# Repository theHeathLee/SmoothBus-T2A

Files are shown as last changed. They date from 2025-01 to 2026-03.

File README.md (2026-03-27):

# SmoothBus T2A

An adaptation of the [SmoothBus project](https://github.com/PegorK/SmoothBus/tree/main) for the early VW bay window bus (Type 2A). Replaces the original fuel gauge mechanism with a servo-driven needle controlled by an ATTiny85 microcontroller, providing smooth movement and a low-fuel LED warning.

## Features

- Smooth servo motion — moves in 1° steps with a moving average filter (35-sample window) to eliminate sender noise
- Low-fuel LED warning when the sender reads in the reserve range
- Boot sweep sequence (empty → full → empty) to verify servo operation
- Compact PCB (~32mm × 14mm) designed to fit within the original gauge enclosure
- 3D-printable enclosure included

## How It Works

The ATTiny85 reads the fuel sender resistance via a voltage divider, applies a running average to smooth noisy readings, and drives a servo to the corresponding needle position. Calibration values are sourced from the [TheSamba forum](https://www.thesamba.com/vw/forum/viewtopic.php?t=693930) and tuned for the T2A sender:

| Sender (Ω) | Level | Servo angle |
|---|---|---|
| 10 | Full | 10° |
| 40 | Half | 53° |
| 55 | Quarter | 71° |
| 70 | Reserve | 81° |
| 79 | Empty | 98° |

## Repository Layout

```
SmoothBus-T2A/
├── src/SmoothBus/SmoothBus.ino   # ATTiny85 firmware (Arduino)
├── hardware/
│   ├── SmoothBusT2A.kicad_sch    # Schematic
│   ├── SmoothBusT2A.kicad_pcb    # PCB layout
│   ├── SmoothBusT2A.pdf          # Schematic PDF
│   ├── gerbers.zip               # Gerber files for PCB fabrication
│   ├── bom/ibom.html             # Interactive BOM
│   └── 3D Parts/body.stl         # 3D-printable enclosure
└── pictures/                     # Assembly and finished photos
```

## Resources

- [Interactive BOM](https://htmlpreview.github.io/?https://github.com/theHeathLee/SmoothBus-T2A/blob/main/hardware/bom/ibom.html)
- [Schematic PDF](https://github.com/theHeathLee/SmoothBus-T2A/blob/main/hardware/SmoothBusT2A.pdf)
- [Firmware README](src/README.md) — flashing instructions (Arduino Mega as ISP + ATTinyCore)

## Photos

<table>
  <tr>
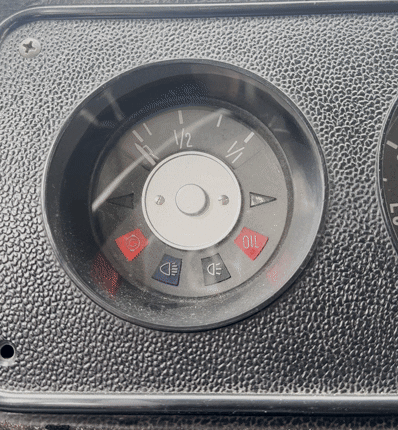
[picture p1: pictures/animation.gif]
Animation
    <td></td>
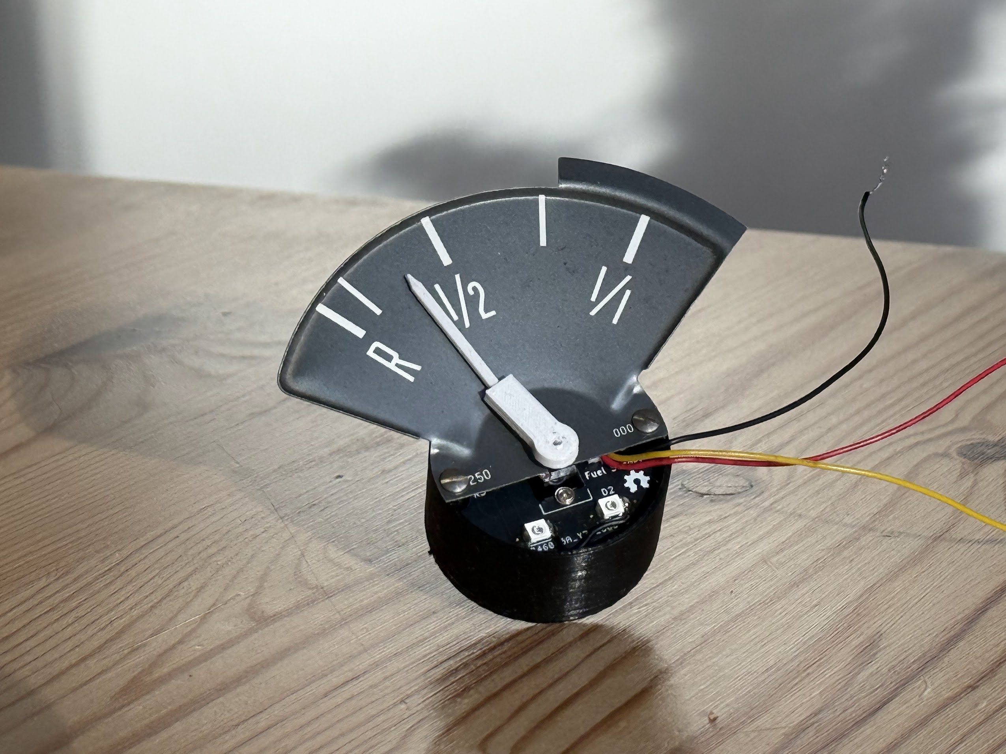
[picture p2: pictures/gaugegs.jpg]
Gauge
    <td></td>
  </tr>
  <tr>
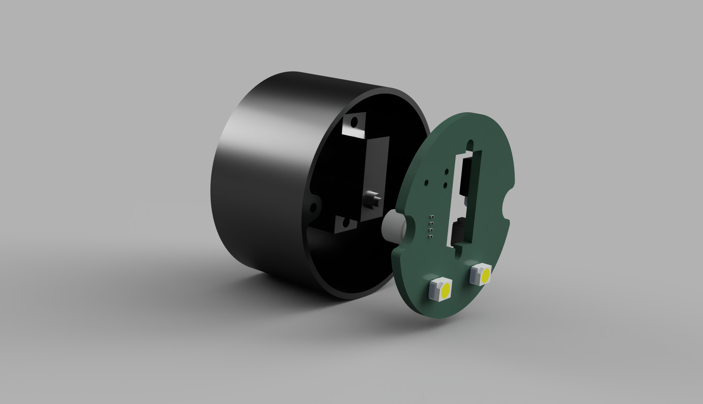
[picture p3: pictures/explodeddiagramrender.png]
Exploded view render
    <td></td>
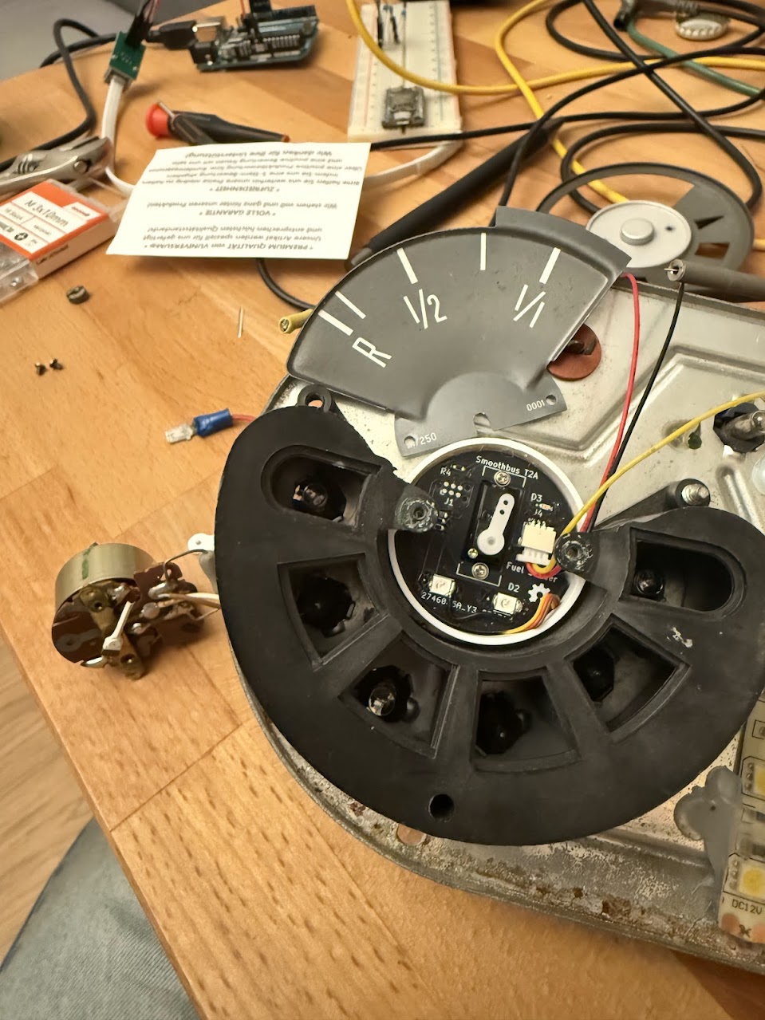
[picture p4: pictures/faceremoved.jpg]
Face removed
    <td></td>
  </tr>
  <tr>
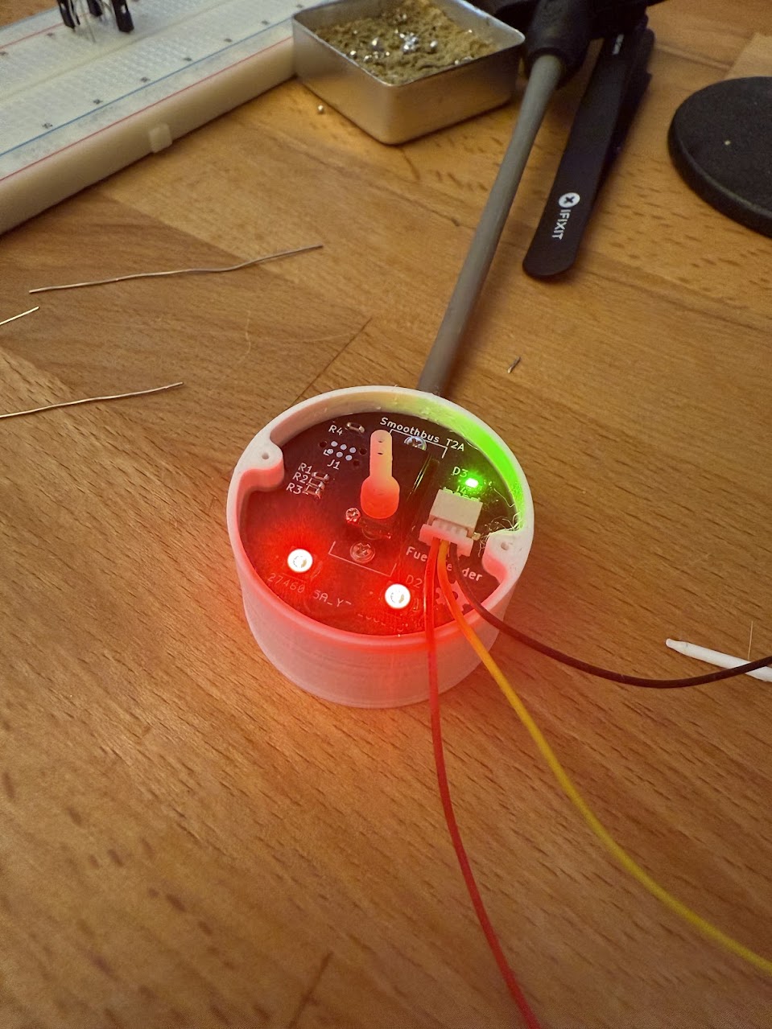
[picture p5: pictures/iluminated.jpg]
Illuminated
    <td></td>
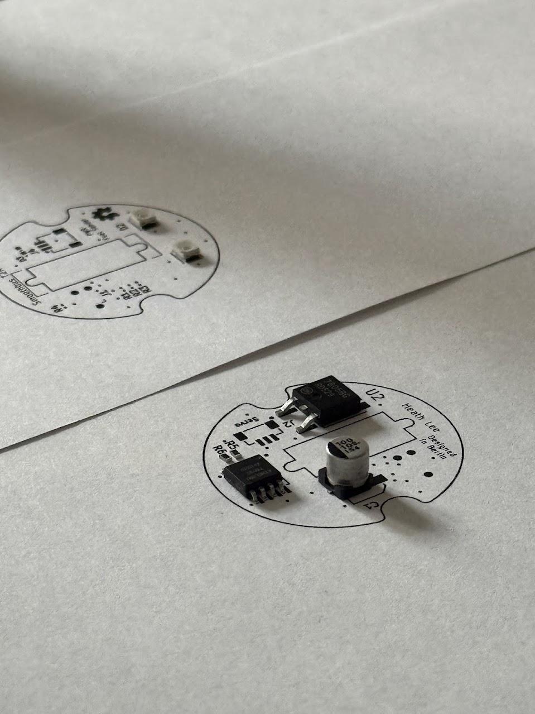
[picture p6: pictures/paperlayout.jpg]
Paper layout
    <td></td>
  </tr>
</table>

## Credits

Original SmoothBus design by [Pegor Karoglanian](https://github.com/PegorK/SmoothBus/tree/main).

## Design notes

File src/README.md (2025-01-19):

# SmoothBus Src

This folder contains the code that gets slapped onto the ATTiny85 chip using the Arduino IDE.

### Dependencies

* [Konde's ATTinyCore library](https://github.com/SpenceKonde/ATTinyCore) - add to your Arduino IDE.

### Flashing

* I used an Arduino Mega2560 as an ISP to flash the ATTiny85 with the programming jig. [Here](https://www.instructables.com/How-to-Burn-ATTiny85-Using-Arduino-Mega/) is a decent write up.
    * Flashed the ATTiny85 with the clock set to 16 Mhz, anything less with introduce more servo jitter.

## Things to improve
* Discard readings that are dramatically different than previous reading. Could be based on percent difference.
* Low fuel warning indicator logic could be improved to not trigger on every time it has a reading in that range. Instead turn the warning lights on if there has been continuous readings in that range (maybe something along the lines of if 20 readings) same with turning them off. This could help reduce flashing warning lights when you take a turn.

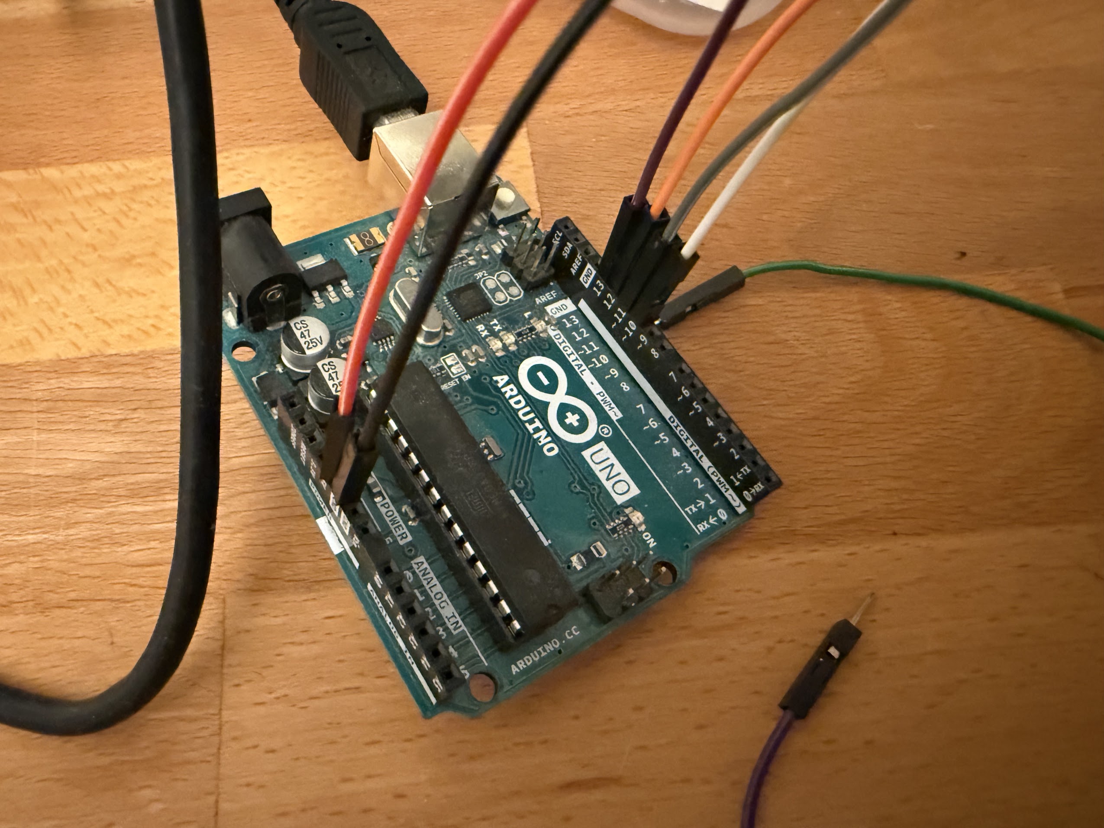
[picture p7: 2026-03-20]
pictures/uno.png

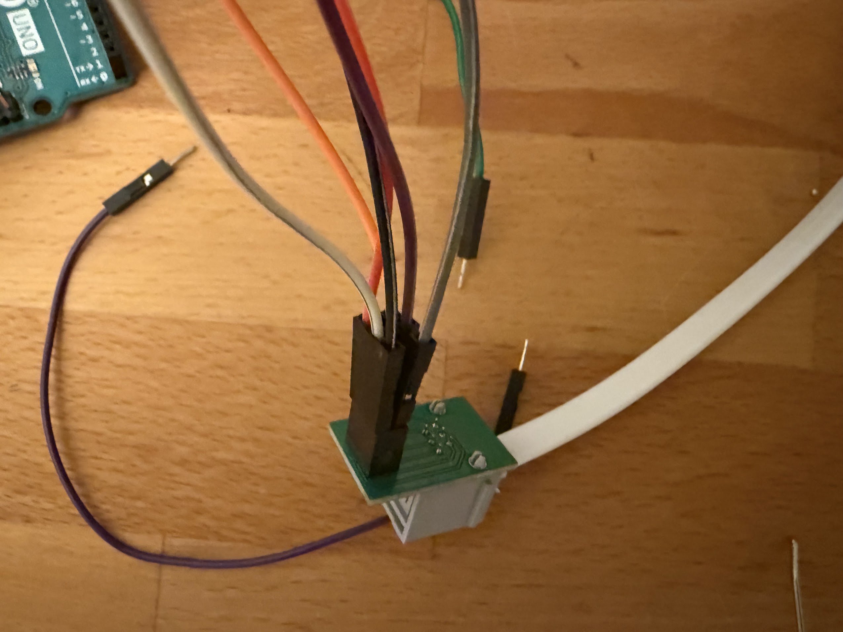
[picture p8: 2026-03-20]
pictures/tagconnect.png

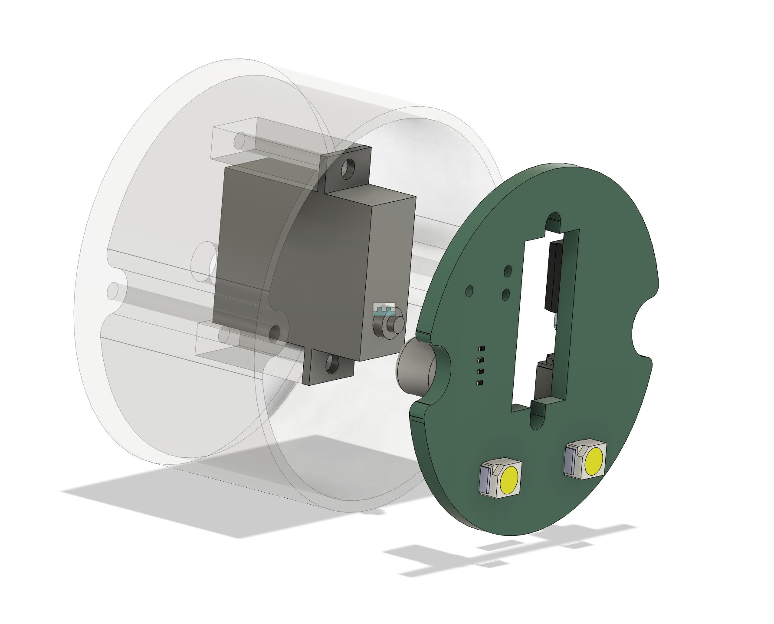
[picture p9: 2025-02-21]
pictures/explodedview.png

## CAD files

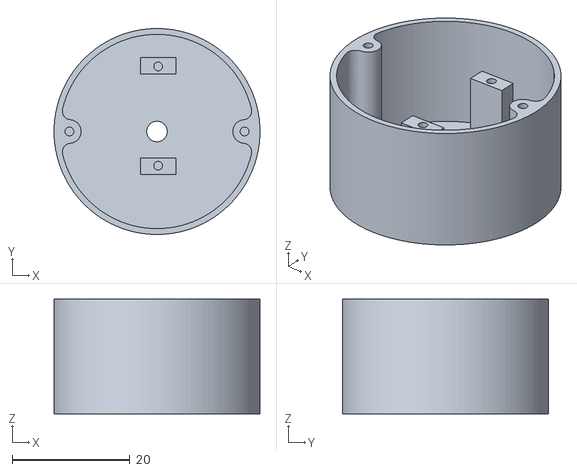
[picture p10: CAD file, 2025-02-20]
hardware/3D Parts/bodyV1.stl
35.0 x 35.0 x 19.5

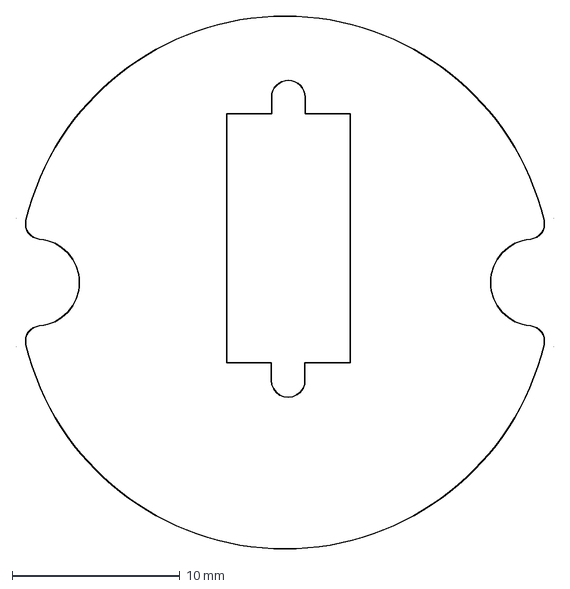
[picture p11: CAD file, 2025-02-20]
hardware/pcbawithholes3.dxf
32.1 x 31.8 mm

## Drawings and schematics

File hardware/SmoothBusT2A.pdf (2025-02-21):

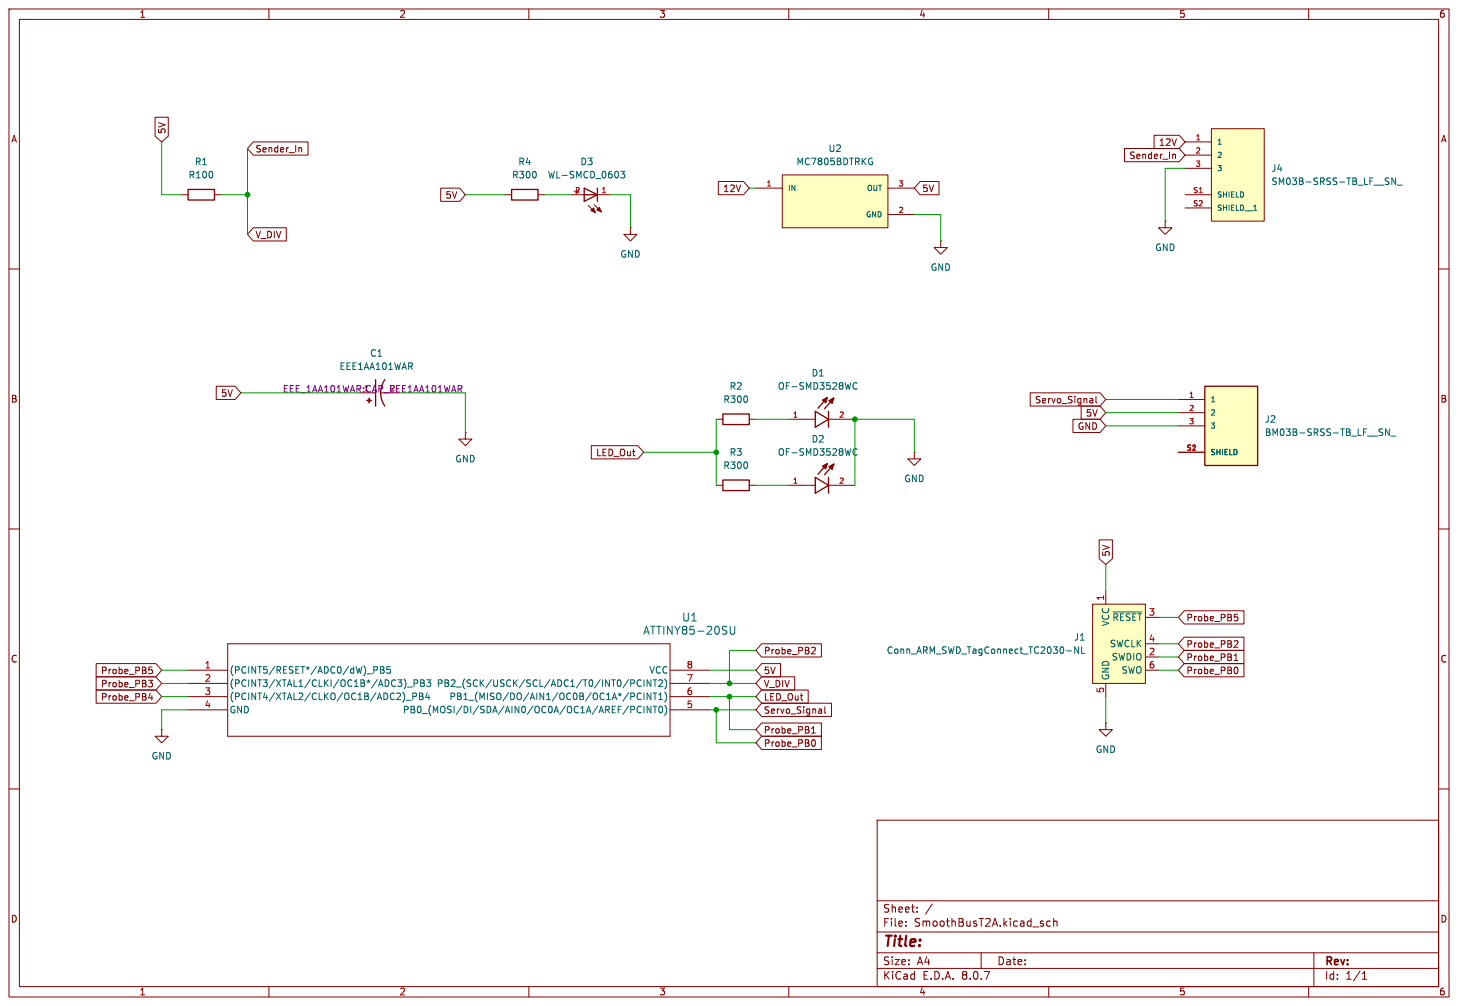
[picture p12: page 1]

1 SWDIO 2 ~{RESET}3 SWCLK 4 GND

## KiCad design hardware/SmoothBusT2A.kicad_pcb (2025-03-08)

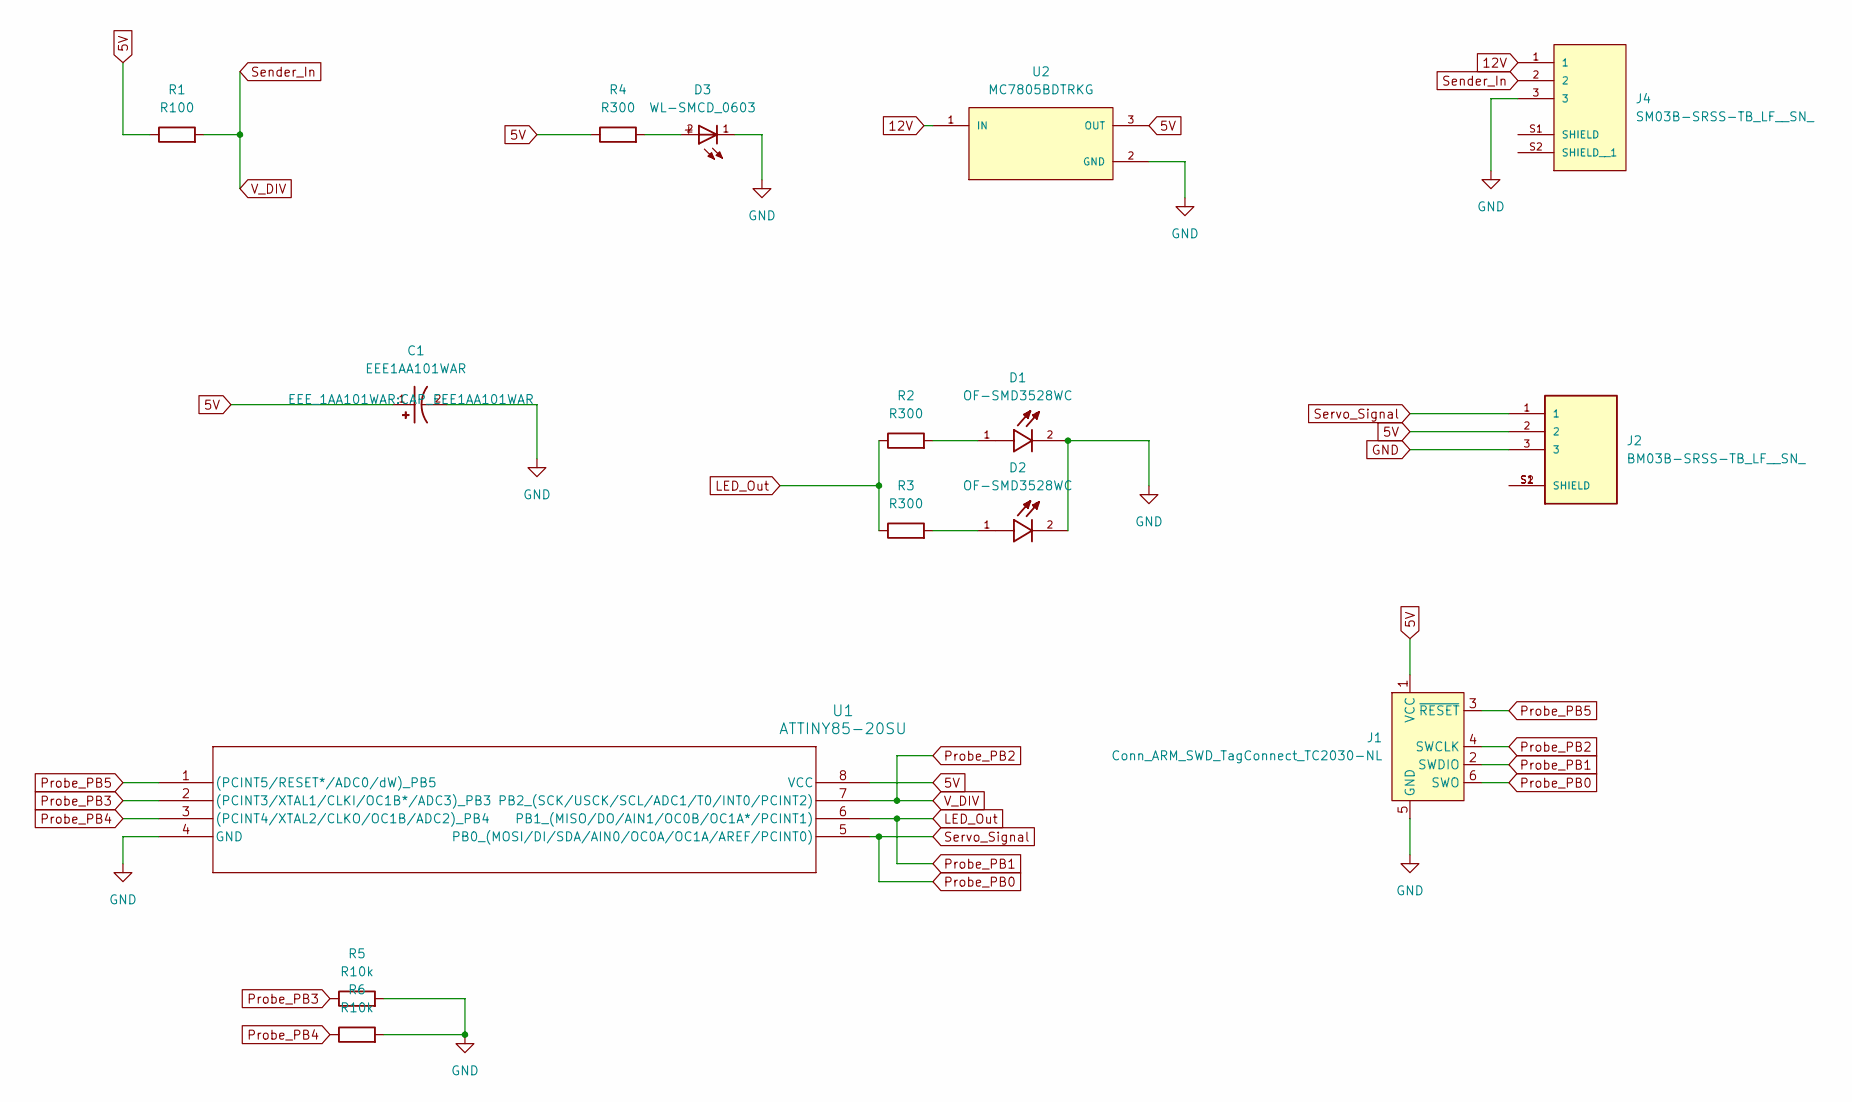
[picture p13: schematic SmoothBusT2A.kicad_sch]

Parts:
C1: EEE1AA101WAR; CAP_EEE1AA101WAR; PARTREV 10-Oct-19
D1, D2: OF-SMD3528WC; LED_OF-SMD3528WC; PARTREV NA
D3: WL-SMCD_0603
J1: Conn_ARM_SWD_TagConnect_TC2030-NL; Tag-Connect_TC2030-IDC-NL_2x03_P1.27mm_Vertical
J2: BM03B-SRSS-TB_LF__SN_; JST_BM03B-SRSS-TB_LF__SN_; PARTREV N/A
J4: SM03B-SRSS-TB_LF__SN_; JST_SM03B-SRSS-TB_LF__SN_
R1: R100; R_0201_0603Metric_Pad0.64x0.40mm_HandSolder
R2, R3, R4: R300; R_0201_0603Metric_Pad0.64x0.40mm_HandSolder
R5, R6: R10k; R_0201_0603Metric_Pad0.64x0.40mm_HandSolder
U1: ATTINY85-20SU; 8S2_ATM
U2: MC7805BDTRKG; DPAK229P990X238-4N; PARTREV 27

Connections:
5V: C1.1, J1.1 (VCC), J2.2, R1.1, R4.1, U1.8 (VCC), U2.3 (OUT)
12V: J4.1, U2.1 (IN)
GND: C1.2, D1.2, D2.2, D3.1, J1.5 (GND), J2.3, J4.3, R5.2, R6.2, U1.4 (GND), U2.2 (GND)
LED_Out: J1.2 (SWDIO), R2.1, R3.1, U1.6 (PB1_(MISO/DO/AIN1/OC0B/OC1A*/PCINT1))
unnamed: D1.1, R2.2
unnamed: D2.1, R3.2
unnamed: D3.2, R4.2
unnamed: J2.S1 (SHIELD), J2.S2 (SHIELD)
Probe_PB0: J1.6 (SWO), J2.1, U1.5 (PB0_(MOSI/DI/SDA/AIN0/OC0A/OC1A/AREF/PC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)
Probe_PB2: J1.4 (SWCLK), J4.2, R1.2, U1.7 (PB2_(SCK/USCK/SCL/ADC1/T0/INT0/PCINT2))
Probe_PB3: R5.1, U1.2 ((PCINT3/XTAL1/CLKI/OC1B*/ADC3)_PB3)
Probe_PB4: R6.1, U1.3 ((PCINT4/XTAL2/CLKO/OC1B/ADC2)_PB4)
Probe_PB5: J1.3 (~RESET), U1.1 ((PCINT5/RESET*/ADC0/dW)_PB5)

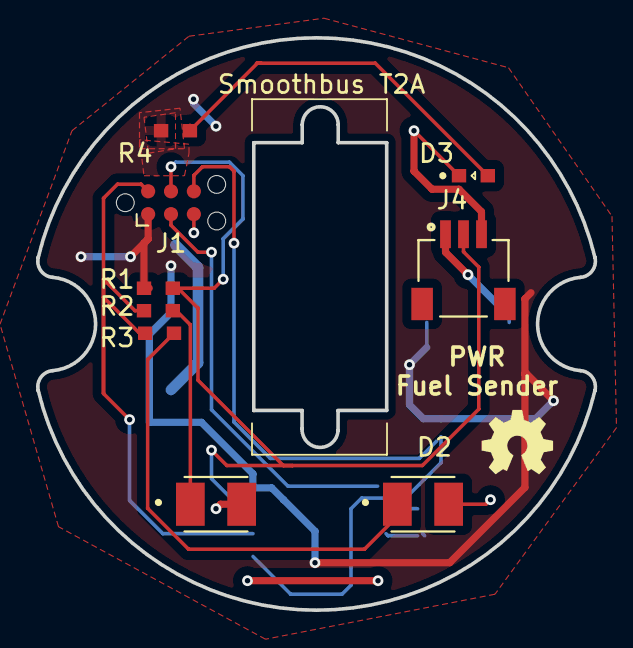
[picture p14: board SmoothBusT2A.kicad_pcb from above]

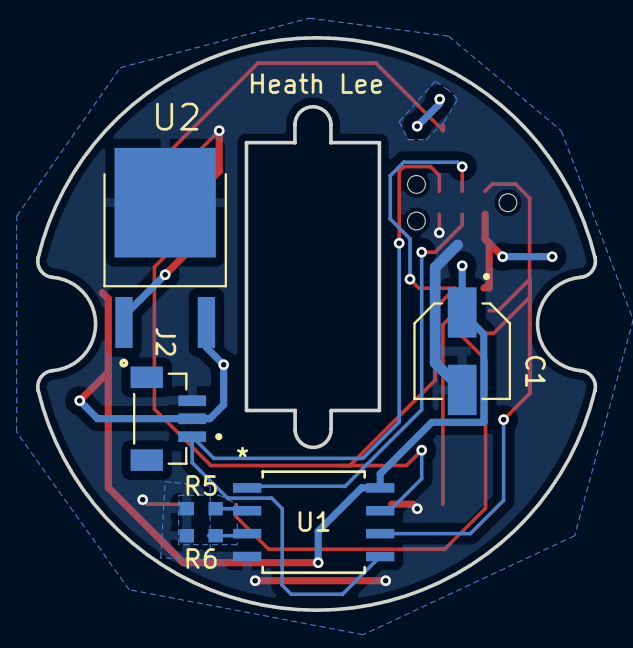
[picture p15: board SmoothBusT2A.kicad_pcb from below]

Board: 2 copper layers, 31.0 x 31.8 mm, 15 parts (6 on the bottom side), 13 nets.

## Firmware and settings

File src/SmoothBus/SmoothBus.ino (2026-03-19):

//==========================================
// Title:  SmoothBus.ino
// Author: Pegor Karoglanian
// Date:   11/1/24
// Notes:  Code for SmoothBus fuel gauge conversion for VW Bus.
//==========================================

#include <ATTinyCore.h>
#include <Arduino.h>
#include <Servo.h>

#ifdef DEBUG
  #define SERVO_PIN 9
  #define LOW_FUEL_LED 2
#else
  #define SERVO_PIN 0
  #define LOW_FUEL_LED 1
#endif

#define WINDOW_SIZE 35 // window for moving average
#define SENDER_PIN 1 // analog pin
#define R1 101 // resistor for voltage divider
#define VIN 5
#define VREF 5
#define SERVO_STEP_DELAY 15 // delay between steps in servo moves for smoother motion
#define SERVO_DEADBAND 2 // minimum position change (degrees) before moving servo
#define READ_DELAY_MS 200 // fuel read frequency
#define MIN_RAW 10 // fuel sender tabs should be bent so that at FULL its 10 ohms
#define MAX_RAW 79 // fuel sender tabs should be bent so that at EMPTY its 79 ohms

class SmoothBus {
  private:
    Servo servo;
    int servo_pin;
    int sender_pin;
    int low_fuel_indicator_pin;

    int raw = 0;
    // resistance values based on info from here:
    // https://www.thesamba.com/vw/forum/viewtopic.php?t=693930
    int in_full = 10;
    int in_half = 40;
    int in_quarter = 55;
    int in_r = 70; 
    int in_empty = 79;

    // servo values that matched my setup
    int out_full = 10;
    int out_half = 53;
    int out_quarter = 71;
    int out_r = 81;
    int out_empty = 98;


    int servo_pos = out_empty;
    int index = 0;
    bool filled = false;
    float avg_arr[WINDOW_SIZE];
    float total = 0;
  
  public:
    SmoothBus(int servo_pin, int sender_pin, int low_fuel_indicator_pin) {
      this->servo_pin = servo_pin;
      this->sender_pin = sender_pin;
      this->low_fuel_indicator_pin = low_fuel_indicator_pin;

      init();
    }

    void init() {
      pinMode(this->low_fuel_indicator_pin, OUTPUT);
      servo.attach(this->servo_pin);
      servoBootSequence();
    }

    void servoBootSequence() {
      servo.write(this->out_empty);
      delay(1000);
      for (int pos = this->out_empty; pos >= this->out_full; pos -= 1) { // goes from out_empty degrees to out_full degrees
        servo.write(pos);
        delay(13);
      }
      delay(500);
      for (int pos = this->out_full; pos <= this->out_empty; pos += 1) { // goes from out_full degrees to out_empty degrees
        servo.write(pos);
        delay(13);
      }
      delay(750);
      servo.detach();
    }

    void readFuelSender() {
      this->raw = analogRead(this->sender_pin);
#ifdef DEBUG
  Serial.print("Analog read: ");
  Serial.println(this->raw);
#endif
      if(this->raw) {
        float Vout = (raw/1023.0) * VREF;
        float fuel_sender = R1 * (Vout/(VIN - Vout));
        if (fuel_sender < MIN_RAW) {
          fuel_sender = MIN_RAW;
        } else if (fuel_sender > MAX_RAW) {
          fuel_sender = MAX_RAW;
        }
        // possible TODO - drop values that are a certain percentage over the last
        // but keep track of back to back repetition for scenarios like filling up tank
        int current_avg = round(runningAverage(fuel_sender));
#ifdef DEBUG
  Serial.print("Current Avg: ");
  Serial.println(current_avg);
#endif

        // map to ranges based on fuel sender calibration data from above forum.
        int sender_pos = 0;
        int out_min = 0;
        int out_max = 0;
        int in_min = 0;
        int in_max = 0;

        digitalWrite(this->low_fuel_indicator_pin, LOW);
        if (current_avg >= this->in_full && current_avg <= this->in_half) { // 1/2 to FULL
          out_min = this->out_full;
          out_max = this->out_half;
          in_min = this->in_full;
          in_max = this->in_half;
#ifdef DEBUG
  Serial.println("1/2 to FULL");
#endif
        } else if (current_avg >= (this->in_half-1) && current_avg <= this->in_quarter) { //  1/4 to 1/2
          out_min = this->out_half;
          out_max = this->out_quarter;
          in_min = this->in_half;
          in_max = this->in_quarter;
#ifdef DEBUG
  Serial.println("1/4 to 1/2");
#endif
        } else if (current_avg >= (this->in_quarter-1) && current_avg <= this->in_r) { // R to 1/4
          out_min = this->out_quarter;
          out_max = this->out_r;
          in_min = this->in_quarter;
          in_max = this->in_r;
#ifdef DEBUG
  Serial.println("R to 1/4");
#endif
        } else { // E to R
          out_min = this->out_r;
          out_max = this->out_empty;
          in_min = this->in_r;
          in_max = this->in_empty;
          digitalWrite(this->low_fuel_indicator_pin, HIGH);
#ifdef DEBUG
  Serial.println("E to R");
#endif
        }

        sender_pos = out_min + (out_max - out_min) * (current_avg - in_min) / (in_max - in_min);
        if (abs(sender_pos - this->servo_pos) > SERVO_DEADBAND) {
          setServoPos(sender_pos);
        }
      }
    }

    void setServoPos(int pos) {
      servo.attach(this->servo_pin);
      // go in steps instead of shoot to position
      while (this->servo_pos != pos) {
        if (pos > this->servo_pos) {
          servo.write(this->servo_pos++);
        } else if (pos < this->servo_pos) {
          servo.write(this->servo_pos--);
        }
        delay(SERVO_STEP_DELAY);
      }
      delay(200); // let servo settle before detaching
      servo.detach();
    }

    float runningAverage(float resistance) {
      if (this->filled) {
          this->total -= this->avg_arr[this->index];
      }

      // Replace the oldest value with the new value
      this->avg_arr[this->index] = resistance;
      this->total += resistance;  // Add the new value to the total

      // Move the index for the next new value
      this->index = (this->index + 1) % WINDOW_SIZE;

      // Check if the window has been filled at least once
      if (this->index == 0) {
          this->filled = true;
      }

      // Calculate and return the average
      float running_average = this->total / (this->filled ? WINDOW_SIZE : this->index);
      return running_average;
    }
};



void setup() {
#ifdef DEBUG
  Serial.begin(9600);
#endif
}

void loop() {
  SmoothBus smooth_bus(SERVO_PIN, SENDER_PIN, LOW_FUEL_LED);
  while(1) {
    smooth_bus.readFuelSender();
    delay(READ_DELAY_MS);
  }
}

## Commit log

2025-01-28 added parts to pcb
    [SmoothBusT2A.kicad_pcb, SmoothBusT2A.kicad_sch]
2025-02-20 routing traces
    [SmoothBusT2A.kicad_pcb, SmoothBusT2A.kicad_sch, pcbawithholes3.dxf]
2025-02-21 finish tracing and add bom
    [SmoothBusT2A.kicad_pcb, SmoothBusT2A.kicad_sch]
2025-02-21 create schematic pdf
2025-02-21 make 3d parts folder
    [body.stl]
2025-02-21 add gerbers
2025-03-08 version 1
    [SmoothBusT2A.kicad_pcb, SmoothBusT2A.kicad_sch, bodyV1.stl]
2026-03-19 reduce servo jitter
